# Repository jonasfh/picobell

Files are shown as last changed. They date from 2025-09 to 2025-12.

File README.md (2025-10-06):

# PicoBell Doorbell Project

Prosjekt for å gjøre eksisterende porttelefon smartere.   Målet er å kunne motta ringesignaler på mobil, og åpne døren fra en egen app – uten å miste dagens funksjonalitet.

Se [docs](docs/) for detaljert dokumentasjon.

## Struktur

    doorbell-project/
    │
    ├── pico/                # Alt for Pico-mikrokontrolleren
    │   ├── firmware/        # C++/Micropython/Pico SDK kode
    │   └── docs/            # Notater om HW-tilkobling, skjema osv.
    │
    ├── server/           # PHP-backend (API)
    │   ├── public/       # Web-root (index.php)
    │   ├── src/          # PHP-kode (controllers, services)
    │   ├── config/       # Konfig (dotenv, secrets, firebase.json)
    │   ├── vendor/       # Composer dependencies
    │   ├── composer.json # Composer config
    │   └── composer.lock
    │
    ├── mobile/              # Klient-app
    │   ├── android/         # Android-kode
    │   ├── ios/             # (ev. senere)
    │   └── shared/          # Felles ressurser (ikon, assets, logoer)
    │
    ├── docs/                # Arkitekturdiagrammer, flyt, API-spec
    │
    └── .gitignore

## Systemoversikt

```mermaid
flowchart LR
    subgraph Mobile["Android app"]
        M1["Bruker logger inn med Google"]
        M2["Får JWT fra server"]
        M3["Kaller /profile-endepunkter"]
    end

    subgraph Web["Web (test/cli)"]
        W1["Kan kalle auth/google"]
        W2["Kan teste med JWT"]
    end

    subgraph Server["Picobell server (Slim/PHP)"]
        S1["AuthController"]
        S2["ProfileController"]
        S3["DevicesController"]
        S4["ApartmentsController"]
        S5["AdminController"]
    end

    subgraph DB["SQLite (dev) / Postgres (prod senere?)"]
        D1["users"]
        D2["devices"]
        D3["apartments"]
        D4["user_apartment (role)"]
    end

    M1 --> S1
    W1 --> S1
    S1 --> D1
    S1 --> M2
    S1 --> W2
    M3 --> S2
    M3 --> S3
    M3 --> S4
    S2 --> D1
    S3 --> D2
    S4 --> D3
    S4 --> D4
    S5 --> D1
    S5 --> D2
    S5 --> D3
```

## Arkitektur (oversikt)

```mermaid
flowchart LR
    subgraph HW[Raspberry Pi Pico + Porttelefon]
        BELL[Ringesignal deteksjon] --> PICO
        BTN["Døråpner-knapp (relé)"] --> PICO
        PICO -- "MikroPython/C++" --> WIFI((WiFi))
    end

    WIFI --> SERVER[Python backend på NREC]

    subgraph SERVER
        API["REST API (FastAPI/Flask)"]
        QUEUE["Message Queue (opsjon)"]
        FCM[Firebase Cloud Messaging]
    end

    SERVER <--> API
    API --> FCM

    FCM --> APP[Android/iOS App]
    APP <--> API
```

## Komponenter

* Pico: Leser ringesignalet, styrer døråpner.
* Server: Python (FastAPI/Flask). Håndterer API, push-varsler, autentisering.
* Mobilapp: Android (og evt. iOS). Mottar varsler, gir bruker mulighet til å åpne dør.

## Database

Det er behov for en database for følgende oppgaver:

* Registrering av brukere
* Registrering av leiligheter/picoer

```mermaid
erDiagram
    USERS {
        int      id
        string   email
        string   password_hash
        string   display_name
        string   phone
        datetime created_at
        datetime updated_at
    }

    APARTMENTS {
        int      id
        string   name
        string   address
        string   pico_id
        string   fw_version
        string   metadata
        datetime created_at
    }

    USER_APARTMENT {
        int      id
        int      user_id
        int      apartment_id
        string   role
        datetime created_at
    }

    DEVICE_TOKENS {
        int      id
        int      user_id
        string   token
        string   platform
        datetime created_at
        datetime last_seen
    }

    AUDIT_LOG {
        int      id
        int      user_id
        string   event_type
        string   details
        string   ip
        datetime created_at
    }

    USERS ||--o{ USER_APARTMENT : has
    APARTMENTS ||--o{ USER_APARTMENT : has
    USERS ||--o{ DEVICE_TOKENS : owns
    USERS ||--o{ AUDIT_LOG : generates
```

## Sikkerhet

* Pico fungerer kun som klient, aldri åpen port mot internett.
* Server kjører med TLS (nginx som reverse proxy).
* Push-varsler håndteres via Firebase (Android) og evt. APNs (iOS).
* API autentisering med tokens (JWT eller lignende).

## Authentisering

```mermaid
sequenceDiagram
    participant U as User (Android/Web)
    participant G as Google OAuth
    participant S as Picobell Server
    participant DB as Database

    U->>G: Login with Google
    G-->>U: Google ID token
    U->>S: POST /auth/google (ID token)
    S->>G: Verify ID token
    G-->>S: Token valid + user info
    S->>DB: Lookup user by email
    DB-->>S: User found or new created
    S-->>U: JWT (id, email, role)

    U->>S: Call protected endpoint (with Bearer JWT)
    S->>S: Verify JWT signature
    S->>DB: (optional) fetch user details
    DB-->>S: User info
    S-->>U: Response
```

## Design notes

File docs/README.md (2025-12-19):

# Dokumentasjon – Doorbell Project

Her beskrives arkitektur, kommunikasjon og oppsett mer detaljert.

---

## Arkitektur

```mermaid
flowchart LR
    subgraph HW["Raspberry Pi Pico + Porttelefon"]
        BELL["Ringesignal deteksjon"] --> PICO
        BTN["Døråpner-knapp (relé)"] --> PICO
        PICO -- "MikroPython/C++" --> WIFI((WiFi))
    end

    WIFI --> SERVER[Python backend på NREC]

    subgraph SERVER
        API["REST API (FastAPI/Flask)"]
        FCM[Firebase Cloud Messaging]
    end

    SERVER <--> API
    API --> FCM

    FCM --> APP[Android/iOS App]
    APP <--> API
```

## Dataflyt

1. Noen ringer på døren
    Pico detekterer signal → sender HTTP request til server.
2. Server mottar signal
    Backend registrerer hendelsen → sender push-varsel via FCM/APNs.
3. Mobilapp mottar varsel
    Bruker får notifikasjon → kan åpne appen og velge "Åpne dør".
4. Åpne dør
    App kaller API på server → server sender kommando til Pico → Pico trigger "åpne dør"-relé.

## Komponenter

* Pico: Leser ringesignalet, styrer døråpner.
* Server: Python (FastAPI/Flask). Håndterer API, push-varsler, autentisering.
* Mobilapp: Android (og evt. iOS). Mottar varsler, gir bruker mulighet til å åpne dør.

## Sikkerhet

* Pico fungerer kun som klient, aldri åpen port mot internett.
* Server kjører med TLS (nginx som reverse proxy).
* Push-varsler håndteres via Firebase (Android) og evt. APNs (iOS).
* API autentisering med tokens (JWT eller lignende).

## Videre arbeid

* [ ]  Implementere Pico-firmware for å sende events.
* [ ]  Lage Python-server med REST-endepunkter.
* [ ]  Integrere push-varsler.
* [ ]  Utvikle Android-app (MVP).
* [ ]  Teste helheten.

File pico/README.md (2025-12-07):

Picobell pico development and setup
===================================

This directory contains the source code and documentation for the Picobell
device based on the Raspberry Pi Pico W microcontroller. It includes
instructions for setting up MicroPython, BLE provisioning, and file structure
overview.

## Contents

* `src/`: Source code files for the Pico W firmware.
* `flash/`: Directory for files stored on the Pico's flash memory.
* `PICO_MICROPYTHON.md`: Guide for installing MicroPython on the Pico W
* `PICO_THONNY.md`: Instructions for using Thonny IDE with the Pico W
* `PICO_BLE.md`: Guide for testing BLE provisioning on the Pico W
* `OVERVIEW.md`: Overview of the Picobell Pico firmware features and architecture
* `README.md`: This readme file.

## Getting Started

To get started with Picobell Pico development, follow the guides in the
`PICO_MICROPYTHON.md` and `PICO_THONNY.md` files to set up your environment and
install MicroPython on your Pico W device.

For BLE provisioning testing, refer to the `PICO_BLE.md` guide.

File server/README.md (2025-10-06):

# Slim Framework 4, Medoo og Phinx

Dette prosjektet bruker [Slim Framework 4](https://www.slimframework.com/) som
web-rammeverk, [Medoo](https://medoo.in/) som database-abstraksjonslag, og
[Phinx](https://phinx.org/) for database-migrasjoner.

## Konfigurasjonsfiler (`server/config/`)

Se egen [README.md](config/README.md) for detaljer om konfigurasjon av
applikasjonen.

## Database

Databasen er SQLite for utvikling, og lagres som default i `/tmp/dev.sqlite3`.

## Få test token fra google Google OAuth Playground

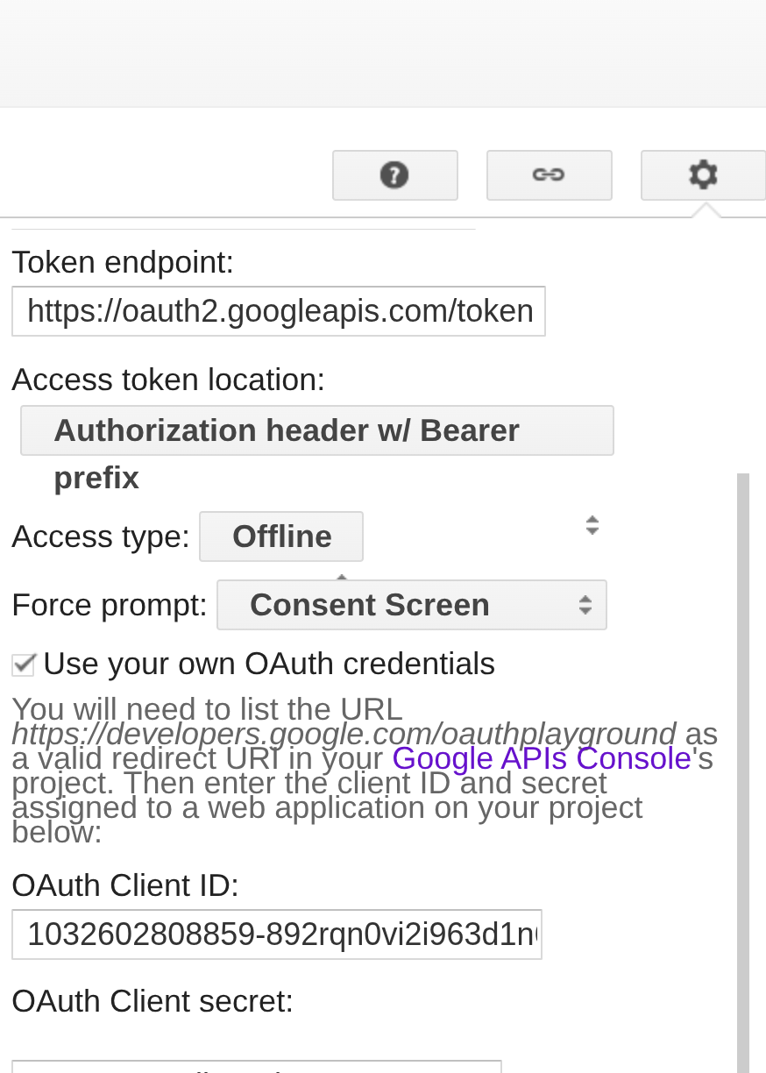
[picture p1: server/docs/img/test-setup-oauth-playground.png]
Screenshot Oauth playground


* Oauth-appen må auth redirect uri være med, i [console for Google Cloud](https://console.cloud.google.com/):
    - https://developers.google.com/oauthplayground
* Gå til OAuth 2.0 Playground [Oauth playground](https://developers.google.com/oauthplayground)
* Konfigurer for test (se screenshot):
    - Legg inn i tannhjul oppe til høyre
    - Use own OAuth credentials
    - Legg inn client id og secret
* Velg Google OAuth2 API v2 → https://www.googleapis.com/auth/userinfo.email.
* Klikk deg gjennom flowen → du får et ID Token under "Step 2".
* Kopiér det og bruk i Postman når du tester POST /auth/google-login.

## Oversikt over endepunkter

```mermaid
flowchart LR
    A["/auth"]
    A1["POST /auth/google"]

    B["/profile"]
    B1["GET /profile"]
    B2["/profile/devices"]
    B21["GET /profile/devices"]
    B22["POST /profile/devices/register"]
    B3["/profile/apartments"]
    B31["GET /profile/apartments"]
    B32["POST /profile/apartments"]

    C["/admin"]
    C1["..."]

    A --> A1
    B --> B1
    B --> B2
    B2 --> B21
    B2 --> B22
    B --> B3
    B3 --> B31
    B3 --> B32
    C --> C1
```

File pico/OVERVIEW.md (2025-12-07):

# Picobell Pico Firmware

Firmware for Raspberry Pi Pico W som håndterer:

* BLE provisioning (Wi-Fi konfigurering via mobil)
* Unik enhets-identifikasjon (MAC-adresse)
* Sikker lagring av Wi-Fi-credentials
* Normal drift når Wi-Fi er konfigurert
* Boot-logikk for å starte provisioning på knapp

Dette er en del av Picobell-systemet hvor mobilapp, server og Pico-
enheter samarbeider om å administrere dørklokke- og adgangsfunksjoner.

---

## Pico W Pinout

Pico W Pinout

In mermaid:

```mermaid
graph TD
    A[Pico W] --> B(GPIO Pins)
    A --> C(Wi-Fi Antenna)
    A --> D(USB Port)
```

---

## BLE Provisioning Flow

```mermaid
sequenceDiagram
    participant User
    participant Pico as Pico W
    participant BLE as BLE (GATT)
    participant App as Mobile App

    User->>Pico: Hold button (3s) to enter setup mode
    Pico->>BLE: Start advertising Picobell-Setup-XXXX

    App->>BLE: Scan and connect
    BLE->>App: device_info service exposed

    App->>BLE: Read device_id
    App->>Server: Register device_id to user

    App->>BLE: Write wifi_ssid
    App->>BLE: Write wifi_password
    App->>BLE: Write wifi_cmd "connect"

    Pico->>Pico: Attempt Wi-Fi connection
    Pico->>BLE: Notify wifi_status "connecting"

    Pico->>BLE: Notify "connected:192.168.1.20"
    Pico->>Pico: Store credentials to flash
    Pico->>Pico: Disable BLE and enter normal mode
```

## 📁 Filstruktur

pico/
├── README.md
├── src/
│   ├── main.py
│   ├── ble_provision.py
│   ├── wifi_manager.py
│   ├── device_info.py
│   ├── buttons.py
│   ├── led.py
│   ├── storage.py
├── flash/
│   ├── wifi.json
│   └── secrets.json (optional)
├── tools/
│   ├── mpremote.sh
│   ├── build-fw.sh
└── tests/
    ├── test_ble.md
    ├── test_wifi.md

## 🧠 Komponenter

### main.py
Bestemmer modus basert på:om lagrede credentials finnes om brukeren holder inne knappen

### ble_provision.py

Eksponerer GATT-services:device_info
wifi_prov Tar imot SSID/passord og kommandoer fra app.

### wifi_manager.py

Kobler til Wi-Fi, henter status og returnerer resultat til BLE.

### storage.py

Lagrer credentials trygt i flash som JSON.

### device_info.py

Gir unik enhets-ID (MAC) og firmware-versjon.

### buttons.py

Oppdager knapp for å trigge provisioning.

### led.py

Viser status:langsomt blink = provisioningrask blink = connectingfast lys = connectedpulserende = error🧪 Testing uten appDu kan test-provisione hele enheten med nRF Connect:Scan → Picobell-Setup-XXXXKoble tilLes device_idSkriv wifi_ssidSkriv wifi_passwordSkriv wifi_cmd = "connect"Observer wifi_status notifications📦 DeployBruk

### tools/mpremote.sh:

### tools/mpremote.sh put src/*.py :🧭

## Videre arbeid

OTA-oppdateringer (opsjon)
Hardening av BLE (pairing + nonce)
Logging av hendelser til serverEOF

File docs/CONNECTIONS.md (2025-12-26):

Koblingsskjema for dørtelefon / Pico
====================================

Enkel oversikt over hvordan piko kan kobles opp

## Strømforsyning og signal-tap
```mermaid
flowchart TD

    %% Raw supply
    TBP["TB +<br>28–30 V"] --> INP["IN+<br>LM2596"]
    TBN["TA -<br>GND"] --> INN["IN-<br>LM2596"]

    %% Regulator
    INP --> REG["LM2596<br>Regulator"]
    INN --> REG

    %% Regulated output
    REG --> OUTP["OUT+<br>5 V"]
    REG --> OUTN["OUT-<br>GND"]

    %% Pico power
    OUTP --> C1["100 nF"]
    OUTP --> C2["10 µF"]
    C1 --> PGND["Pico GND"]
    C2 --> PGND
    OUTP --> VCC["Pico VSYS / VCC"]
    OUTN --> PGND

    %% Signal tap (BEFORE regulator)
    TBP --> R1["91 kΩ"]
    R1 --> R2["10 kΩ"]
    R2 --> PGND

    R2 --> ADC["Pico ADC"]

    %% Protection
    ADC --> D1["Schottky<br>til 3.3 V"]
    D1 --> PICO33["Pico 3.3V rail"]

    %% Test potentiometer
    OUTP --> POT["10 kΩ<br>Potmeter (kun test)"]
    POT --> PGND
    POT --> ADC

```

## Fokus på signal-tap for dørtelefon

```mermaid

flowchart TD

    PORT["28–30 V<br>Porttelefon-linje"]

    %% Power path
    PORT --> BREG["LM2596<br>(buck-regulator)"]
    BREG --> VSYS["Pico VSYS (5V)"]

    %% Signal tap
    PORT --> R1["R1 91kΩ"]
    R1 --> R2["R2 10kΩ"]
    subgraph FILTER ["Støyfilter"]
        R2 --> FILT["100 nF<br>RC-filter"]
        FILT --> SER["10kΩ serie-motstand"]
    end
    SER --> ADC["Pico ADC input"]

    %% Protection
    ADC -->|clamp| DIO["Schottky diode<br>til 3.3V"]
    DIO --> V33["3.3V rail"]

    R2 --> GND
    BREG --> GND
```

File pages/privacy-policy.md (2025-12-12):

# Privacy Policy

_Last updated: 2024-12-12_

This Privacy Policy describes how **Picobell** ("the App") handles user data.
The App is developed and maintained by **Jonas Fagnastøl Henriksen**.

The App requires Google Sign-In for authentication and uses the user's Google
account email address. No other personal information is collected or stored.

---

## 1. Information We Collect

### 1.1 Google Account Information
When you sign in, the App receives your **Google email address** (and optionally
your display name, depending on your Google account settings).
This information is used **solely for authentication and identifying your
account** inside the App.

We do *not* access:

- contacts
- files
- calendar
- phone number
- Google Drive
- or any other Google profile data

### 1.2 User-Provided Address Label
The App allows you to optionally set a **label** (e.g., “Leilighet 2A” or
similar) to identify your doorbell/device. Initially a generic label is
provided, Picobell-xxxx.

This label:

- is provided by you
- is not validated or linked to your real home address
- is only used to help you identify your devices in the App

No other personal information is collected.

The App does **not** collect location data, analytics, device identifiers, or
tracking information.

---

## 2. How We Use Your Information

We use the collected information exclusively to:

- authenticate you via Google Sign-In
- associate your account with your doorbell/device
- display your chosen device label in the App

We do **not** use your data for:

- marketing
- profiling
- analytics
- advertising
- selling or sharing with third parties

Your data is never used beyond what is required to provide the App's core
functionality.

---

## 3. Data Storage

The following data may be stored securely on our server:

- your Google email address
- your optional device label

No other user data is stored.

We do not store passwords — authentication is handled entirely by Google.

---

## 4. Data Sharing

We do **not** share any personal data with:

- third parties
- advertisers
- analytics services
- data brokers

We only send the minimal data needed to deliver notifications or messages to
your registered device.

---

## 5. Children’s Privacy

The App is not intended for children under the age of 13.
No personal information about children is knowingly collected.

---

## 6. User Rights

You may request:

- deletion of your data
- export of your data
- correction of your device label

To request this, contact us using the information below.

If you remove the App or stop using it, you may also request that your stored
email address and device labels be deleted.

---

## 7. Changes to This Policy

Updates to this policy will be published on this page.
Continued use of the App after updates means you accept the changes.

---

## 8. Contact

For any questions or requests regarding this Privacy Policy:

**Email:** jonas.f.henriksen@gmail.com
**Website:** https://github.com/jonasfh/picobell

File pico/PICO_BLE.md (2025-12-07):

# Testing BLE Provisioning on the Pico W

## Overview

Picobell Pico W exposes a Bluetooth Low Energy (BLE) service that lets you set
Wi-Fi credentials from any BLE scanner app (e.g. nRF Connect). This guide shows
how to verify provisioning works without the Picobell mobile app.

---

## What You Need

* A Raspberry Pi Pico W flashed with MicroPython
* The file `ble_provision.py` uploaded to the device
* A BLE scanner app such as **nRF Connect** (Android/iOS)

---

## How to Test

### 1. Boot Pico in provisioning mode

* Ensure there is **no `/flash/wifi.json`** on the Pico
  (delete it from Thonny if needed)
* Or: hold the provisioning button if your project supports it

The Pico will begin advertising over BLE.

---

### 2. Open nRF Connect

* Open **Scanner**
* Look for a device named:
  `Picobell-XXXX`
  (`XXXX` is the last 4 hex of the MAC)

If the name shows as *N/A*, ensure `gap_name` is set in your code.

---

### 3. Connect to the device

Tap the device, then tap **Connect**.

You should now see the provisioning service with characteristics.

---

### 4. Write SSID

Find the `UUID_SSID` characteristic and write a UTF-8 string, e.g.
my-wifi

---

### 5. Write password

Find `UUID_PASS` and write the password.

---

### 6. Start connection

Write the string:
connect
…to the `UUID_CMD` characteristic.

---

### 7. Watch status

Observe notifications from `UUID_STATUS`:

* `connecting`
* `connected:<ip>`
* `failed`

---

### 8. Verify credentials saved

Open Pico’s file system in Thonny:
/flash/wifi.json
The file should contain:
{ "ssid": "...", "pwd": "..." }

---

## Mermaid: BLE Provisioning Flow

```mermaid
sequenceDiagram
    participant User
    participant App as BLE App
    participant Pico

    User->>App: Open nRF Connect
    App->>Pico: Connect over BLE
    User->>Pico: Write SSID
    User->>Pico: Write Password
    User->>Pico: Write "connect"
    Pico->>Pico: Attempt Wi-Fi connect
    Pico->>App: Notify status
    Pico->>Filesystem: Save wifi.json
```

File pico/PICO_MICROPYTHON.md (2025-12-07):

# Installing MicroPython on Raspberry Pi Pico W

## Overview

This guide explains how to flash the newest MicroPython firmware onto a Pico W.

---

## Requirements

* Raspberry Pi Pico W
* USB cable
* A computer (Windows, macOS, Linux)

---

## Steps

### 1. Download the latest firmware

Go to:

[https://micropython.org/download/rp2-picow/](https://micropython.org/download/rp2-picow/)

Download the newest `.uf2` file, for example:
micropython-1.25.0-picow.uf2

---

### 2. Put Pico in bootloader mode

1. Hold the **BOOTSEL** button
2. Plug in the USB cable
3. Release the button

A disk named `RPI-RP2` appears.

---

### 3. Flash MicroPython

Drag the `.uf2` file onto the `RPI-RP2` drive.

The Pico reboots automatically into MicroPython.

---

### 4. Verify installation

Open Thonny or any serial terminal and run:

```python
import sys
sys.implementationYou should see MicroPython 1.22+
```

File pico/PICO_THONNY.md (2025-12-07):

markdown=<<'EOF'

# Developing for Pico W Using Thonny

## Overview

Thonny provides the simplest workflow for editing and uploading files to the
MicroPython device. This guide covers installing, configuring, and working
around common environment issues.

---

## Install Thonny

### Recommended

Install Thonny using Python 3.11:

`python3.11 -m pip install thonny`

Thonny often fails on distro-packaged Python builds. A venv keeps it stable.

---

## Running Thonny from a virtualenv

```bash
    python3.11 -m venv venv
    source venv/bin/activate
    pip install thonny
    thonny
```

This avoids issues with older GTK libraries and plugin mismatches.

---

## Configure Interpreter

Inside Thonny:

Tools → Options → Interpreter

Select:

MicroPython (Raspberry Pi Pico)

Choose the serial port corresponding to the Pico.

---

## Show File Browser

If you don’t see the device files:

View → Files

Two panes appear: local and device.

---

## Upload Files

Right-click a local file → choose:

Upload to /

or use:

File → Save copy to → MicroPython device

---

## Autostart main.py

MicroPython automatically runs:

1. `boot.py` (optional)
2. `main.py` (on every boot)

Place your app logic in `main.py`.

---

## Common Problems

### Thonny doesn’t detect the Pico

* Ensure you’re not using USB hubs
* Try another cable
* Reflash MicroPython

### Write errors

The Pico’s flash can fill up quickly. Delete old files in the device panel.

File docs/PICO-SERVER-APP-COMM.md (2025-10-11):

Kommunikasjon mellom Pico og Android/iOS App
============================================

Diagrammet nedenfor beskriver kommunikasjonen mellom Pico, serveren (API) og 
enhetene (appene) ved bruk av Firebase Cloud Messaging (FCM).

```mermaid
sequenceDiagram
    participant P as Pico
    participant S as Server (API)
    participant D as Devices (App)
    
    P->>S: POST /doorbell/ring (med pico_serial)
    S->>D: FCM-notification (alle devices i samme apartment)
    D->>S: POST /doorbell/open (bruker trykker "åpne")
    loop 3 minutter
        P->>S: GET /doorbell/status?pico_serial=XYZ
        S-->>P: { "open": true/false }
    end
    alt open = true
        P->>P: Åpne døra
    else
        P->>P: Gjør ingenting
    end
```

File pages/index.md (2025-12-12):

# Dokumentasjon

Velkommen! Her finner du alle støtte­dokumenter for appen.

## 📄 Innhold

- [Privacy Policy](privacy-policy.md)
- [Terms of Service](terms-of-service.md)
- [Support](support.md)

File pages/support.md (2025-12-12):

# Support

If you need help with **Picobell**, you can reach us using the contact
information below.

We aim to respond to all requests within a reasonable time.

---

## 📧 Contact Email

**jonas.f.henriksen@gmail.com**

Use this email for:

- technical issues
- account deletion requests
- bug reports
- feature suggestions
- general questions

---

## 🛠 Troubleshooting Tips

Before contacting support, please try the following:

1. Restart the App
2. Check for the latest update in Google Play
3. Ensure your device has internet access
4. Reauthenticate with Google Sign-In
5. Verify permissions if relevant

---

## 🔐 Data Deletion Requests

If you want your account data removed (email + device labels), contact us at
the email above.
We will delete all stored data associated with your Google account.

---

## 🌐 Additional Resources

- **Privacy Policy:** https://github.com/jonasfh/picobell/blob/main/pages/privacy-policy.md
- **Terms of Service:** https://github.com/jonasfh/picobell/blob/main/pages/terms-of-service.md

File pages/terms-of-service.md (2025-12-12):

# Terms of Service

_Last updated: 2024-12-12_

These Terms of Service ("Terms") govern your use of **Picobell**
("the App"). By installing or using the App, you agree to these Terms.

If you do not agree, please uninstall the App and discontinue use.

---

## 1. Use of the App

You may use the App only for lawful purposes and in accordance with these Terms.
You agree not to misuse the App, interfere with its operation, or attempt to
access data or functionality you are not authorized to use.

---

## 2. User Account and Google Sign-In

The App requires authentication using your **Google account**.
By using Google Sign-In, you grant the App permission to access your Google
email address for the purpose of identifying your account.

You are responsible for maintaining the security of your device and Google
account credentials.

---

## 3. Data Collected

The App processes the following minimal data:

- Your Google email address (for authentication)
- An optional device label you assign (e.g., a name for your doorbell/device)

The App does not collect any other personal information.

For full details, see the **Privacy Policy**.

---

## 4. Acceptable Use

You may not use the App to:

- engage in illegal activities
- attempt to disrupt or circumvent the App's functionality
- impersonate others
- interfere with system security or server operation

---

## 5. Ownership and Intellectual Property

All code, design, features, and content in the App are the property of
**[Your Name / Organization]**, unless otherwise noted.
You may not copy, distribute, or modify the App without permission.

---

## 6. Disclaimer of Warranties

The App is provided on an “as is” and “as available” basis.
No guarantees are made regarding:

- uptime
- data accuracy
- feature availability
- error-free operation

You use the App at your own risk.

---

## 7. Limitation of Liability

To the fullest extent permitted by law,
**[Your Name / Organization]** shall not be liable for:

- loss of data
- damage to device
- service interruptions
- indirect or consequential damages

---

## 8. Termination

We may suspend or terminate your access to the App if you violate these Terms
or misuse the service.

You may stop using the App at any time by uninstalling it.

---

## 9. Changes to These Terms

The Terms may be updated from time to time.
Updates will be published on this page.
Continued use of the App after changes means acceptance of the updated Terms.

---

## 10. Contact

If you have any questions about these Terms:

**Email:** jonas.f.henriksen@gmail.com
**Website:** https://github.com/jonasfh/picobell

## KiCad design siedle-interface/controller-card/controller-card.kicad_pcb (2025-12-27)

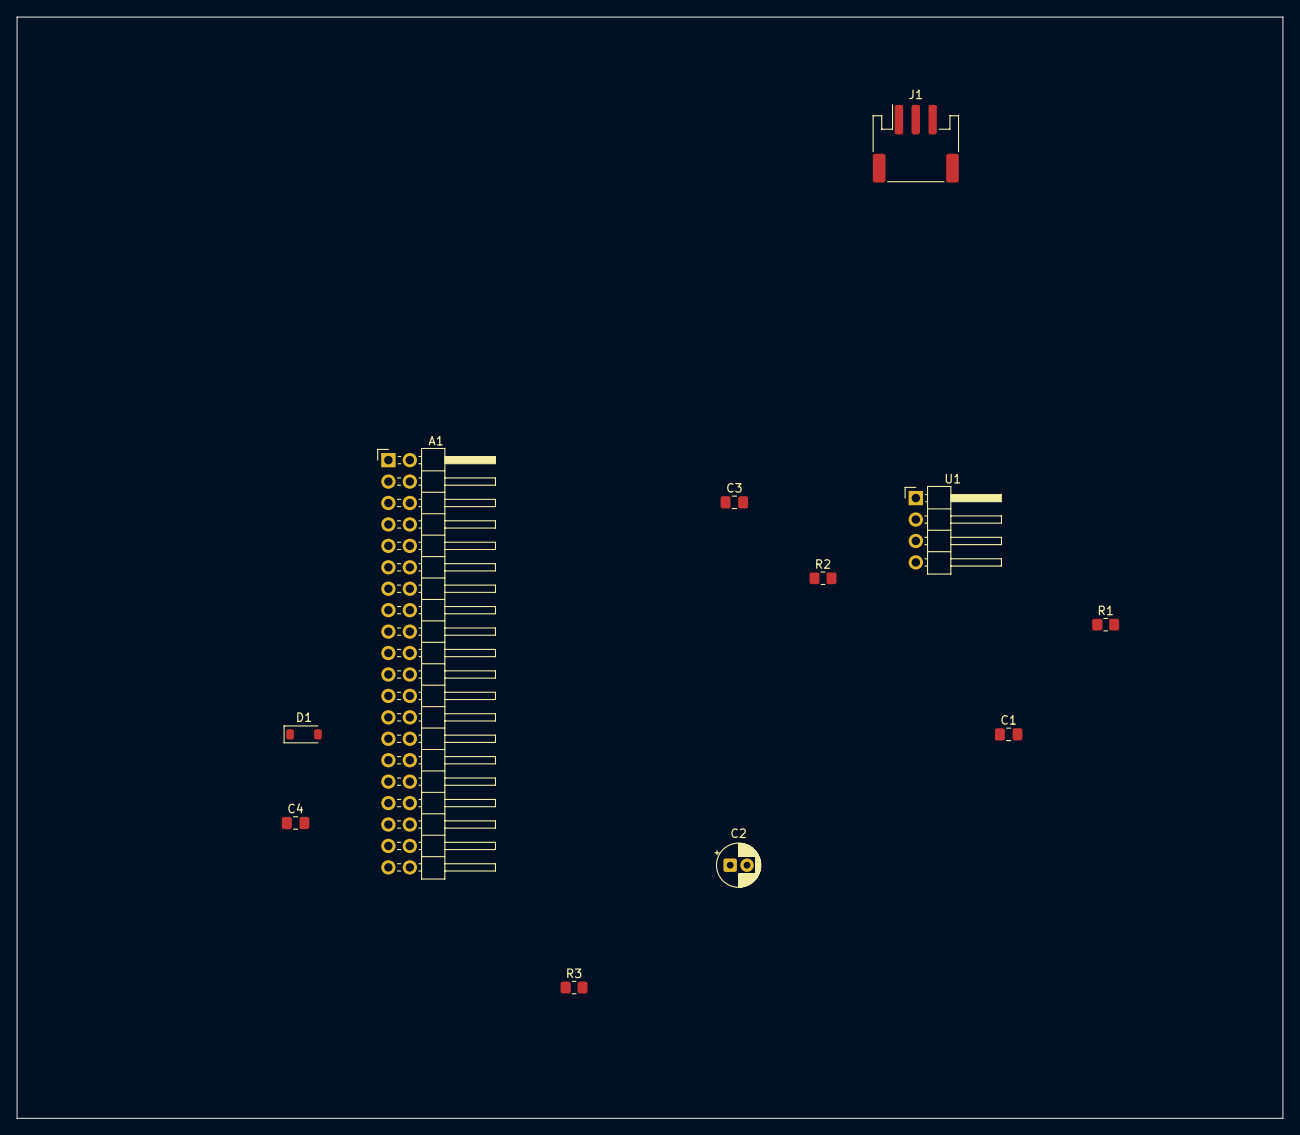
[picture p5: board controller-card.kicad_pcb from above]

Board: 2 copper layers, 150.0 x 130.5 mm, 11 parts (0 on the bottom side), 7 nets, no tracks yet.

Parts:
A1: RaspberryPi_Pico_W; PinHeader_2x20_P2.54mm_Horizontal
C1, C3, C4: 100nF; C_0805_2012Metric_Pad1.18x1.45mm_HandSolder
C2: 10uF; CP_Radial_D5.0mm_P2.00mm
D1: Schottky, clamp; D_SOD-123
J1: Conn_01x03; JST_PH_S3B-PH-SM4-TB_1x03-1MP_P2.00mm_Horizontal
R1: 100kOhm; R_0805_2012Metric_Pad1.20x1.40mm_HandSolder
R2: 10kOhm; R_0805_2012Metric_Pad1.20x1.40mm_HandSolder
R3: 10kOhm seriemotstand; R_0805_2012Metric_Pad1.20x1.40mm_HandSolder
U1: LM2596S MODULE; PinHeader_1x04_P2.54mm_Horizontal

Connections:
/+27.7V: J1.2, R1.1, U1.1 (VIN)
/GND: A1.3 (GND), A1.8 (GND), A1.13 (GND), A1.18 (GND), A1.23 (GND), A1.28 (GND), A1.38 (GND), C1.2, C2.1, C3.1, R2.2, U1.2 (OUT)
/Out+ 5V: A1.39 (VSYS), C2.2, C3.2, U1.4 (FB)
/Ring på - signal <3.3V: A1.31 (GPIO26_ADC0), D1.1 (K), R3.2
/Use 3V3 as ADC reference: A1.35 (ADC_VREF), A1.36 (3V3), C4.2, D1.2 (A)
unnamed: A1.33 (AGND), C4.1
unnamed: C1.1, R1.2, R2.1, R3.1

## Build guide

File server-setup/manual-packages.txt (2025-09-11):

apt-listchanges
base-files
bash
bsdutils
cloud-init
composer
curl
dash
diffutils
eatmydata
findutils
git
grep
grub-pc
gzip
hostname
init
libeatmydata1
libwrap0
linux-virtual
login
ncurses-base
ncurses-bin
ncurses-term
nginx
openssh-server
openssh-sftp-server
php-cli
php-curl
php-fpm
php-mbstring
php-xml
python-babel-localedata
python3-babel
python3-jinja2
python3-json-pointer
python3-jsonpatch
python3-jsonschema
python3-markupsafe
python3-pyrsistent
python3-serial
python3-tz
qemu-guest-agent
shim-signed
ssh-import-id
ubuntu-minimal
ubuntu-server
ubuntu-standard
unzip
util-linux

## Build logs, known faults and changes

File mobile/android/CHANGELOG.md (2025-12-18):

Changelog for the Picobell Android application
==============================================

## Version 1.0.5 (2025-12-18)

- Build app with new google services version, includes new Oauth client ID

## Version 1.0.4 (2025-12-14)

- Align apk file before signing to fix install issues.

## Version 1.0.3 (2025-12-13)

- Sign apk file before publishing release
- Fix deploy pipeline to publish the signed apk file

## Version 1.0.2 (2025-12-13)

- Minor changes to deploy pipeline

## Version 1.0.1 (2025-12-12)

- Fix deploy issue publishing apk-file

## Version 1.0.0 (2025-12-12)

- First release of the Picobell Android application

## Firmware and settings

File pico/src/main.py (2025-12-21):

# main.py - Boot + Wi-Fi + BLE + long-press reboot + ring detection
import time
import machine
import network
import ujson
import urequests
from ble_provision import BLEProvision
from version import FW_VERSION

print("Firmware version:", FW_VERSION)

BTN_PIN = 15          # long-press → reboot
RING_PIN = 10         # short press → "ring" event
WIFI_FILE = "/flash/wifi.json"

btn = machine.Pin(BTN_PIN, machine.Pin.IN, machine.Pin.PULL_UP)
ring = machine.Pin(RING_PIN, machine.Pin.IN, machine.Pin.PULL_UP)

LED = machine.Pin("LED", machine.Pin.OUT)
LED.off()

LED_MODE_WIFI = 1
LED_MODE_BLE = 2


led_mode = None
led_last_toggle = 0
led_state = 0


def led_toggle():
    global led_state
    led_state ^= 1
    LED.value(led_state)


def led_update():
    global led_last_toggle, led_state

    now = time.ticks_ms()

    if led_mode == LED_MODE_WIFI:
        # Kort blink hvert 2. sekund

        if time.ticks_diff(now, led_last_toggle) > 5000:
            LED.on()
            led_state = 1
            led_last_toggle = now

        if led_state == 1 and time.ticks_diff(now, led_last_toggle) > 100:
            LED.off()
            led_state = 0

    elif led_mode == LED_MODE_BLE:
        # Toggle hvert 500 ms
        if time.ticks_diff(now, led_last_toggle) > 500:
            led_toggle()
            led_last_toggle = now



# ------------------------
# Utility functions
# ------------------------
def has_wifi():
    try:
        with open(WIFI_FILE) as f:
            data = ujson.load(f)
            return ("ssid" in data) and ("pwd" in data)
    except:
        return False


def load_wifi():
    with open(WIFI_FILE) as f:
        return ujson.load(f)


def connect_wifi(ssid, pwd, timeout=20):
    wifi = network.WLAN(network.STA_IF)
    wifi.active(True)
    wifi.connect(ssid, pwd)
    print("Connecting:", ssid)

    t0 = time.ticks_ms()
    while time.ticks_diff(time.ticks_ms(), t0) < timeout * 1000:
        if wifi.isconnected():
            print("Wi-Fi OK:", wifi.ifconfig())
            return True
        time.sleep(0.3)

    print("Wi-Fi failed.")
    return False


def long_press(pin, hold_ms=10000):
    if pin.value() == 0:
        print("Button press start")
        t0 = time.ticks_ms()
        while pin.value() == 0:
            dt = time.ticks_diff(time.ticks_ms(), t0)
            if dt > hold_ms:
                return True
            time.sleep(0.1)
    return False


def short_press(pin, max_ms=300):
    # LOW = pressed; detect short momentary press
    if pin.value() == 0:
        print("Detecting short press...")
        t0 = time.ticks_ms()
        while pin.value() == 0:
            # debounce hold
            time.sleep(0.01)
        dt = time.ticks_diff(time.ticks_ms(), t0)
        return dt < max_ms
    return False


def start_ble(max_time=300):
    print("BLE start")
    prov = BLEProvision()
    prov.start()

    t0 = time.ticks_ms()
    while True:
        if prov.is_provisioned:
            print("Provision OK → reboot")
            time.sleep(0.5)
            machine.reset()

        if time.ticks_diff(time.ticks_ms(), t0) > max_time * 1000:
            print("BLE timeout")
            break

        led_update()
        time.sleep(0.5)


def send_ring_event(api_key):
    url = "https://picobell.no/doorbell/ring"

    headers = {
        "Authorization": "Apartment " + api_key,
        "Content-Type": "application/json",
        "X-FW-Version": FW_VERSION,
    }

    payload = {}

    try:
        print("POST:", url)
        r = urequests.post(url, headers=headers, json=payload)
        print("POST status:", r.status_code)
        r.close()
    except Exception as e:
        print("POST failed:", e)

def get_device_api_key():
    # Attempt load from wifi.json (add later in provisioning)
    try:
        with open(WIFI_FILE) as f:
            data = ujson.load(f)
            if "device_api_key" in data:
                return data["device_api_key"]
    except:
        pass

    # fallback using MAC
    wlan = network.WLAN(network.STA_IF)
    wlan.active(True)
    mac = wlan.config("mac")
    return mac.hex()

def check_open_status(api_key):
    url = "https://picobell.no/doorbell/status"

    headers = {
        "Authorization": "Apartment " + api_key,
        "Content-Type": "application/json",
        "X-FW-Version": FW_VERSION,
    }

    try:
        r = urequests.post(url, headers=headers, json={})
        if r.status_code == 200:
            data = r.json()
            return data.get("open", False)

        r.close()
    except Exception as e:
        print("Status check failed:", e)

    return False


def pulse_door(pin, duration=0.3):
    pin.init(machine.Pin.OUT)
    pin.value(0)
    time.sleep(duration)
    pin.init(machine.Pin.IN, machine.Pin.PULL_UP)


# ------------------------
# Boot logic
# ------------------------
print("Booting...")

device_api_key = get_device_api_key()

if not has_wifi():
    print("wifi.json missing → BLE")
    led_mode = LED_MODE_BLE
    start_ble()
else:
    cred = load_wifi()
    ok = connect_wifi(cred["ssid"], cred["pwd"], 20)
    if ok:
        led_mode = LED_MODE_WIFI
    else:
        print("Wi-Fi fail → BLE")
        led_mode = LED_MODE_BLE
        start_ble()



# ------------------------
# Main run-loop
# ------------------------
print("Run loop...")

ring_ts = 0
status_counter = 0

while True:
    # Long press = reboot
    if long_press(btn, 10000):
        print("Long-press → reboot")
        time.sleep(0.5)
        machine.reset()

    # Short press = doorbell "ring"
    if short_press(ring, 5000):
        print("RING detected!")
        send_ring_event(device_api_key)
        ring_ts = time.time()
        status_counter = 0
        time.sleep(10)  # dont send multiple rings in a row

    # Check open-status for 5 minutes after ring
    if ring_ts and time.time() - ring_ts < 300:
        status_counter += 1

        if status_counter >= 60:
            status_counter = 0
            print("Checking open status...")
            if check_open_status(device_api_key):
                print("Åpner døren")
                pulse_door(ring)
                ring_ts = 0  # stop further checks

    led_update()
    time.sleep(0.05)

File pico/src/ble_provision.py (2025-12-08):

# ble_provision.py
# BLE provisioning service for Picobell Pico W
from micropython import const
import bluetooth
import network
import binascii
import time
import ujson

FLAG_READ = const(0x02)
FLAG_WRITE = const(0x08)
FLAG_WRITE_NR = const(0x10)
FLAG_NOTIFY = const(0x10)

UUID_DEV_INFO = bluetooth.UUID("12345678-1234-1234-1234-1234567890a0")
UUID_DEV_ID   = bluetooth.UUID("12345678-1234-1234-1234-1234567890a1")
UUID_FW       = bluetooth.UUID("12345678-1234-1234-1234-1234567890a2")

UUID_WIFI     = bluetooth.UUID("12345678-1234-1234-1234-1234567890b0")
UUID_SSID     = bluetooth.UUID("12345678-1234-1234-1234-1234567890b1")
UUID_PASS     = bluetooth.UUID("12345678-1234-1234-1234-1234567890b2")
UUID_CMD      = bluetooth.UUID("12345678-1234-1234-1234-1234567890b3")
UUID_STATUS   = bluetooth.UUID("12345678-1234-1234-1234-1234567890b4")
UUID_API_KEY  = bluetooth.UUID("12345678-1234-1234-1234-1234567890b5")


def adv_payload(name=None, services=None):
    p = bytearray()

    def _append(typ, val):
        p.extend(bytes((len(val) + 1, typ)))
        p.extend(val)

    if name:
        _append(0x09, name.encode())

    if services:
        for uuid in services:
            # konverter UUID til bytes
            b = uuid.uuid if hasattr(uuid, "uuid") else uuid
            if isinstance(b, int):  # 16-bit UUID
                b = b.to_bytes(2, "little")
            elif isinstance(b, bluetooth.UUID):  # noen UUID-objekter
                b = bytes(b)
            # nå er b bytes
            if len(b) == 2:
                _append(0x02, b)
            elif len(b) == 16:
                _append(0x06, b)
            else:
                raise ValueError("Unsupported UUID length")

    return p



class BLEProvision:
    is_provisioned = False  # Indicates if provisioning is done

    def __init__(self):
        self.ble = bluetooth.BLE()
        self.ble.active(True)
        self.ble.irq(self._irq)

        self._connections = set()
        self._ssid = ""
        self._pwd = ""
        self._api_key = ""

        self._wifi = network.WLAN(network.STA_IF)
        self._wifi.active(True)

        mac = self._wifi.config("mac")
        self.device_id = binascii.hexlify(mac).decode()

        devinfo = (UUID_DEV_INFO,
                   ((UUID_DEV_ID, FLAG_READ,),
                    (UUID_FW, FLAG_READ,),))

        wifisrv = (UUID_WIFI,
                   ((UUID_SSID, FLAG_WRITE,),
                    (UUID_PASS, FLAG_WRITE,),
                    (UUID_API_KEY, FLAG_WRITE,),
                    (UUID_CMD, FLAG_WRITE,),
                    (UUID_STATUS, FLAG_NOTIFY,),))

        services = (devinfo, wifisrv)
        handles = self.ble.gatts_register_services(services)

        print("Device id: ", self.device_id)
        (devinfo_handles, wifisrv_handles) = handles
        (self.h_dev_id, self.h_fw) = devinfo_handles

        (self.h_ssid, self.h_pwd,
         self.h_api, self.h_cmd,
         self.h_stat) = wifisrv_handles

        self.ble.gatts_write(self.h_dev_id, self.device_id)
        self.ble.gatts_write(self.h_fw, b"1.0.0")


    def start(self):
        name = "Picobell-" + self.device_id[-4:]
        payload = adv_payload(name=name, services=[UUID_WIFI])
        self.ble.config(gap_name=name)
        self.ble.gap_advertise(100_000, payload)
        scan_resp = adv_payload(name=name)
        self.ble.gap_advertise(100_000, adv_data=payload, resp_data=scan_resp)

    def _irq(self, event, data):
        IRQ_CENTRAL_CONNECT    = 1
        IRQ_CENTRAL_DISCONNECT = 2
        IRQ_GATTS_WRITE        = 3

        print("IRQ event:", event, "data:", data)

        if event == IRQ_CENTRAL_CONNECT:
            self._connections.add(data[0])
            print("Connected to central", data[0])
        elif event == IRQ_CENTRAL_DISCONNECT:
            self._connections.remove(data[0])
            print("Disconnected from central", data[0])
            self.start()
        elif event == IRQ_GATTS_WRITE:
            print("Write to handle", data[1])
            self._write(data[1])

    def _write(self, h):
        print("Writing to handle:", h)
        if h == self.h_ssid:
            self._ssid = self.ble.gatts_read(h).decode()
            print("SSID set to:", self._ssid)
        elif h == self.h_pwd:
            self._pwd = self.ble.gatts_read(h).decode()
            print("Password set to:", self._pwd)
        elif h == self.h_api:
            self._api_key = self.ble.gatts_read(h).decode()
            print("API Key set to:", self._api_key)
        elif h == self.h_cmd:
            cmd = self.ble.gatts_read(h).decode()
            print("CMD received:", cmd)
            if cmd == "connect":
                self._connect()

    def _notify(self, msg):
        for c in self._connections:
            self.ble.gatts_notify(c, self.h_stat, msg)

    def _connect(self):
        print("Connecting?")
        self._notify("connecting")
        self._wifi.disconnect()
        time.sleep(1)
        self._wifi.connect(self._ssid, self._pwd)

        for _ in range(25):
            print(".", end="")
            if self._wifi.isconnected():
                ip = self._wifi.ifconfig()[0]
                self._notify("connected:" + ip)
                print("Connected: ", ip)

                cfg = {"ssid": self._ssid,
                       "pwd": self._pwd,
                       "device_api_key": self._api_key}
                with open("/flash/wifi.json", "w") as f:
                    ujson.dump(cfg, f)

                self.is_provisioned = True
                return
            time.sleep(0.4)

        self._notify("failed")

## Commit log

2025-09-14 Minimal project activity running, printing FCM reg token
2025-09-15 Fix syntax error in flowchart
2025-09-15 Install db drivers
2025-09-17 Add devices table, and seeding for dev
2025-10-05 Add middleware parser, fix medoo insert handling...
    - Also set password to optional in db
2025-10-06 Make sure device always has user
2025-10-06 (#7) register device endpoint
2025-10-06 Move devices and apartm. to profile/ endpoints
2025-10-06 Authenticate to google and register device
2025-10-07 Add last_seen column to devices
2025-10-07 Update device if already exists
2025-12-03 Improve layout. Fix delete device button
2025-12-06 (#21) Broadcast ring events to app, activate open apt button
2025-12-06 (#21) Make sure button is active, and open door when clicked
2025-12-07 Filter output for logged in user
2025-12-07 (#36) Broadcast name correctly to BLE
    [ble_provision.py]
2025-12-07 (#30) Remove 'button' feature
    - Add this later using physical Open - button on the door-phone
2025-12-07 (#30) Support for reboot by long pressing door open (GPIO 15)
    [main.py]
2025-12-07 (#38) Send doorbell ring fra pico
2025-12-07 Update to use device API key for auth
2025-12-08 Add menu to allow pico setup
2025-12-09 (#32) Setup wifi i Pico
2025-12-09 (#32) Add random device_api_key
2025-12-10 Create CONNECTIONS.md for doorphone wiring diagram
    Added a connection diagram for the doorphone and Pico setup.
2025-12-12 (#49) Only allow owner to se edit-button
2025-12-18 Forgot that workflow can filter on paths
2025-12-20 (#83) Versioning pico firmware
2025-12-21 (#85) Led blink status communication
2025-12-26 (#88) First try at schematic of controller card
    [controller-card.kicad_pcb, controller-card.kicad_sch]
2025-12-27 complete schematics
